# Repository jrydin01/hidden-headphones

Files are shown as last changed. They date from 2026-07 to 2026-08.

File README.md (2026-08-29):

# Hidden Headphones

> **Bone conduction headphones that sit on your collarbone, completely hidden under your shirt.**

Hidden Headphones is an open-source hardware project for a discrete, neckband-style bone conduction audio device. The electronics sit in a small rear enclosure while flexible wiring runs through the neckband to vibration pads positioned on the collarbone. The goal is a hands-free listening device that can be worn beneath a shirt.

This repository contains the design documentation, KiCad source files, firmware, bill of materials, and OpenSCAD enclosure model for the current prototype revision.

---

## Overview & Architecture

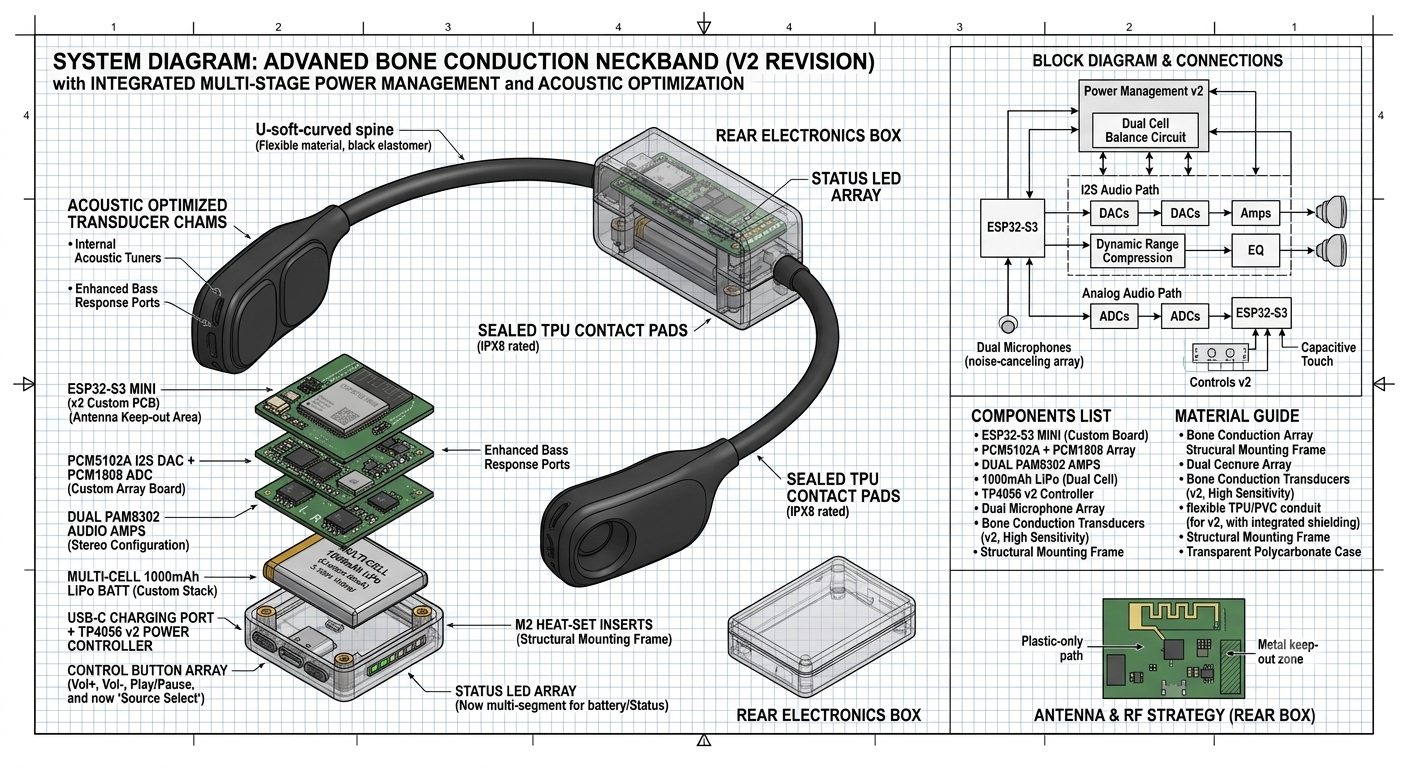
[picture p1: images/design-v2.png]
Design Revision v2


The audio path begins with a phone or computer sending Bluetooth Classic A2DP audio to the original ESP32. The microcontroller outputs stereo PCM audio over I2S to the PCM5102A DAC. Two PAM8302A mono amplifiers drive the left and right bone conduction transducers installed in sealed TPU contact pads.

The project utilizes a custom electronics assembly, dedicated power subsystem, and 3D-printed housing:

* **Core processor:** Original ESP32-WROOM-32 development board with Wi-Fi and Bluetooth Classic
* **Audio input:** Bluetooth A2DP sink running on the ESP32
* **Audio conversion:** PCM5102A stereo I2S DAC
* **Amplification:** Two PAM8302A 2.5 W class-D mono amplifier boards
* **Transducers:** Two 8 ohm, 1 W bone conduction transducers
* **Power:** 3.7 V, 1000 mAh LiPo battery and USB-C TP4056 charging/protection module
* **Controls:** Active-low tactile volume buttons with internal pull-ups
* **Housing:** PETG rear electronics box with flexible TPU neckband sections and sealed contact pads

### Audio and control pins

The current firmware uses the following original ESP32 GPIO assignments:

| Function | GPIO | Notes |
| --- | ---: | --- |
| I2S LRCK / word select | 25 | PCM5102A clock signal |
| I2S BCK / bit clock | 26 | PCM5102A clock signal |
| I2S data out | 22 | PCM5102A serial audio data |
| Volume up | 16 | Active LOW, SW1 |
| Volume down | 17 | Active LOW, SW2 |
| Play/pause | 18 | Active LOW, SW3 |
| Status LED | 19 | LED_STATUS output |

The buttons use a 50 ms software debounce interval. A press changes the Bluetooth sink volume by 10 steps, clamped to the supported range of 0 to 127. The device advertises as **Hidden Headphones**.

## Features

* Hidden collarbone-mounted bone conduction audio
* Wireless Bluetooth A2DP playback
* Stereo output through two independent transducers
* USB-C charging through the TP4056 module
* Dedicated volume up and volume down controls
* Modular rear electronics enclosure
* Flexible cable routing through the neckband
* Open KiCad schematic and PCB source files
* Parametric OpenSCAD enclosure source

## Bill of materials

The complete sourcing list is available in [BOM.csv](BOM.csv). The main assemblies are:

| Category | Part | Quantity |
| --- | --- | ---: |
| Microcontroller | ESP32-WROOM-32 development board | 1 |
| Audio DAC | PCM5102A I2S stereo module | 1 |
| Amplifier | PAM8302A mono amplifier board | 2 |
| Power management | USB-C TP4056 charging and protection module | 1 |
| Battery | 3.7 V 1000 mAh LiPo pack | 1 |
| Audio | Bone conduction transducer, 8 ohm / 1 W | 2 |
| Controls | 6 x 6 x 5 mm tactile push buttons | 3 |
| Hardware | M2 brass heat-set inserts | 4 |
| Wiring | 28 AWG stranded silicone wire | 1 set |
| Printed materials | TPU and PETG filament | 1 spool each |

## Hardware design

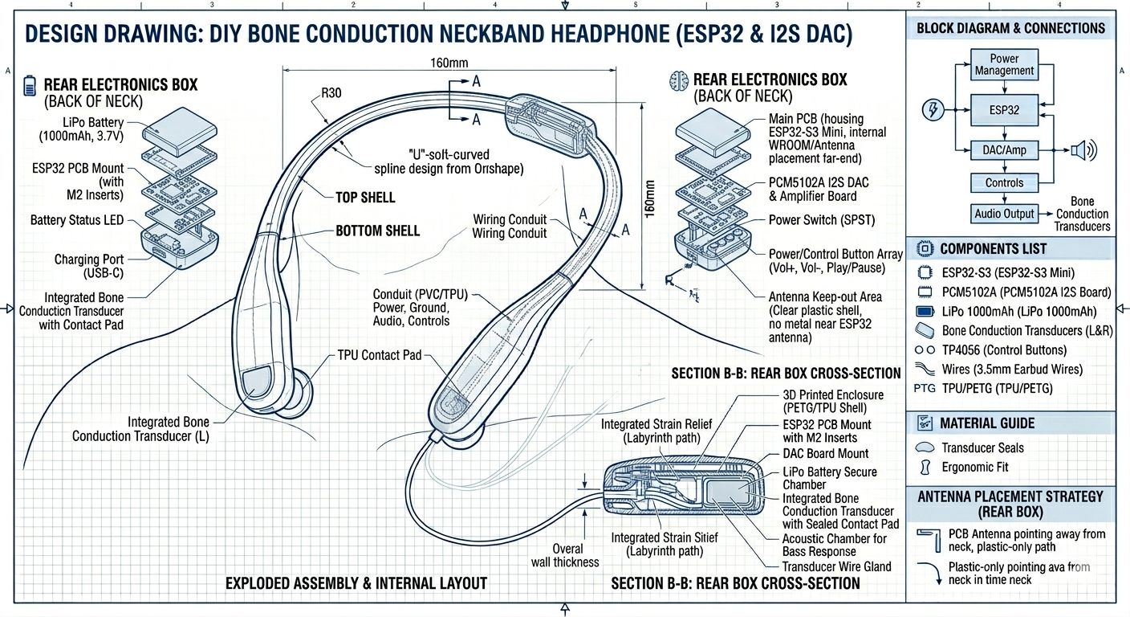
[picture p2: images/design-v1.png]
Design Revision v1


The first design phase established the collarbone contact-pad concept, rear electronics box, battery position, and cable route. The second revision reorganized the electronics around dual amplifier channels and added space for the updated power and audio circuitry.

The rear enclosure is modeled in [rear_box.scad](rear_box.scad). Its current design includes:

* A hollow electronics cavity measuring 55 x 30 x 18 mm internally
* A 2 mm nominal wall thickness
* A USB-C charging-port cutout
* Left and right conduit openings for the neckband wiring
* Four internal PCB mounting posts
* M2 screw and heat-set insert locations
* Separate bottom-case and lid modules for 3D printing

The neckband is intended to use flexible TPU sections for comfort and PETG for the more rigid rear enclosure. The contact pads are designed around sealed TPU housings, with cable strain relief and acoustic tuning features considered in the mechanical revision.

## Firmware

The source firmware is available in [firmware.ino](firmware.ino). It uses the Arduino framework and `ESP32-A2DP` to receive Bluetooth audio and route it over I2S to the PCM5102A and PAM8302A amplifiers. It also handles the three active-low controls and status LED shown in the design diagram.

The firmware currently:

1. Starts a Bluetooth A2DP sink named `Hidden Headphones`.
2. Configures the ESP32 I2S output for the PCM5102A.
3. Enables internal pull-ups for the volume and play/pause buttons.
4. Debounces button input and applies software volume scaling.
5. Controls A2DP playback and the status LED with the play/pause button.
6. Reports startup and control changes over the serial monitor at 115200 baud.

The root-level [firmware.ino](firmware.ino) is also retained as a firmware source snapshot. Keep the two copies synchronized when making firmware changes.

### Flashing and verification

1. Install the ESP32 Arduino board support package and the `ESP32-A2DP` library.
2. Select an original ESP32/WROOM-32 board and its USB serial port.
3. Flash `firmware.ino`.
4. Open a serial monitor at 115200 baud.
6. Confirm the `Bluetooth A2DP sink and PCM5102A I2S output ready` message.
7. Pair a phone or computer with **Hidden Headphones** and verify stereo audio, volume, and play/pause controls.

The pin assignments should be checked against the revised PCB before powering the complete system. The selected GPIOs avoid GPIO0 boot strapping and GPIO1 serial TX conflicts on the ESP32-WROOM-32. The PCB must match this mapping before flashing the firmware.

## Repository structure

```text
.
├── BOM.csv                                      # Component list and sourcing links
├── JOURNAL.md                                   # Project development log and time tracking
├── LICENSE                                      # CC0-1.0 license
├── README.md                                    # Project overview and build guide
├── firmware.ino                                 # Root firmware snapshot
├── firmware.ino                                 # ESP32 Bluetooth A2DP firmware
├── rear_box.scad                                # Parametric rear enclosure model
├── Hidden_Headphones_All_Components_v3.kicad_sch # KiCad schematic
├── Hidden_Headphones_All_Components_v3.kicad_pcb # KiCad PCB layout
├── Hidden_Headphones_All_Components_v3.kicad_pro # KiCad project settings
├── images/                                      # Design, CAD, PCB, and firmware images
└── Untitled/                                    # Additional KiCad working files
```

## Project history

The development log in [JOURNAL.md](JOURNAL.md) records the design process and time spent on each stage:

* **Initial concept:** Established the ESP32 audio architecture, collarbone contact pads, TPU housing, and USB-C rechargeable battery system.
* **CAD and assembly:** Designed the rear electronics box, internal mounting layout, cable conduits, and labyrinth-style strain relief.
* **Component sourcing:** Selected the controller, DAC, amplifiers, charging module, battery, transducers, controls, hardware, wiring, and print materials.
* **Architecture revision:** Added dual PAM8302A amplifiers, revised the power system, and documented the antenna keep-out and sealed contact-pad concepts.
* **Housing model:** Completed the main swept and hollowed enclosure and aligned internal hardware mounting points.
* **PCB design:** Created the KiCad schematic and board layout, resolved schematic and footprint issues, and prepared the design for fabrication.
* **Firmware:** Implemented Bluetooth A2DP playback, I2S routing, volume controls, debouncing, serial output, and the flashing verification procedure.

## Current status

The repository represents a prototype design prepared for hardware fabrication and bring-up. The PCB, firmware, and enclosure should be validated together on assembled hardware, especially the power connections, GPIO assignments, amplifier wiring, battery protection, enclosure clearances, and transducer sealing.

This is an experimental hardware project. Use an appropriate LiPo charging module, inspect batteries and wiring for damage, and do not leave the device charging unattended.

---

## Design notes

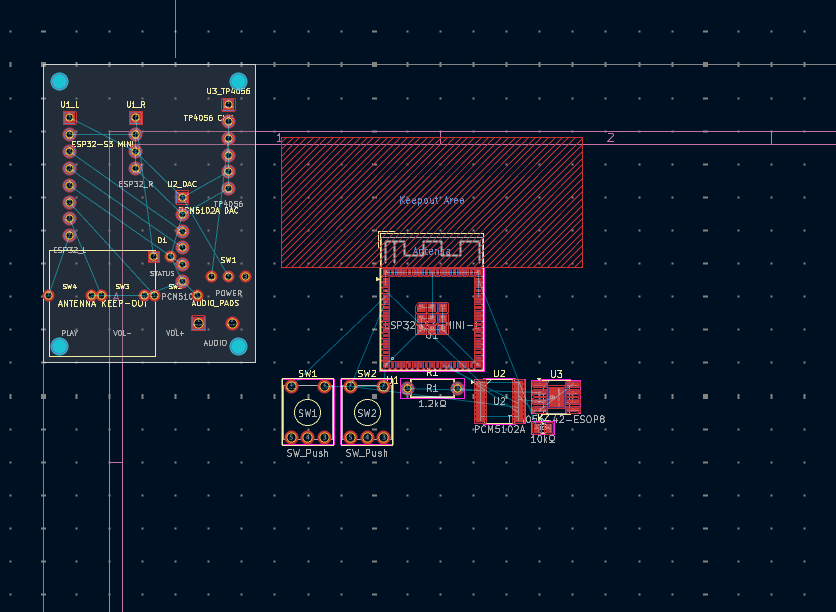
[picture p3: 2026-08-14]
images/pcb_schematic.png

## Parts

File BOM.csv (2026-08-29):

Part Name | Category | Quantity | Description | Link
ESP32-WROOM-32 Board | Microcontroller | 1 | Original ESP32 development board with Wi-Fi and Bluetooth Classic | https://www.aliexpress.com/wholesale?SearchText=ESP32-WROOM-32+development+board
PCM5102A Module | Audio DAC | 1 | I2S Stereo Audio DAC Board | https://www.aliexpress.com/wholesale?SearchText=PCM5102A+I2S+DAC
PAM8302A Board | Amplifier | 2 | 2.5W Class D Mono Audio Amplifier | https://www.aliexpress.com/wholesale?SearchText=PAM8302
TP4056 Module | Power management | 1 | USB-C TP4056 charging and protection module | https://www.aliexpress.com/wholesale?SearchText=TP4056+Type-C
3.7V 1000mAh LiPo Battery | Battery | 1 | 3.7 V 1000 mAh rechargeable LiPo battery pack | https://www.aliexpress.com/wholesale?SearchText=3.7V+1000mAh+LiPo+battery
Bone Conduction Transducers | Audio | 2 | 8 ohm / 1 W bone conduction transducers | https://www.aliexpress.com/wholesale?SearchText=bone+conduction+transducer+speaker
Tactile Push Buttons | Controls | 3 | 6 x 6 x 5 mm tactile push buttons for volume control | https://www.aliexpress.com/wholesale?SearchText=6x6x5mm+tactile+button
M2 Heat-Set Inserts | Hardware | 4 | M2 brass heat-set inserts | https://www.aliexpress.com/wholesale?SearchText=M2+brass+heat+set+inserts
Silicone Wire (28 AWG) | Wiring | 1 set | 28 AWG stranded silicone wire | https://www.aliexpress.com/wholesale?SearchText=28+AWG+silicone+wire
TPU Filament | Printed materials | 1 spool | 1.75 mm black flexible TPU filament | https://www.aliexpress.com/wholesale?SearchText=TPU+filament+black+1.75mm
PETG Filament | Printed materials | 1 spool | 1.75 mm black PETG filament | https://www.aliexpress.com/wholesale?SearchText=PETG+filament+black+1.75mm

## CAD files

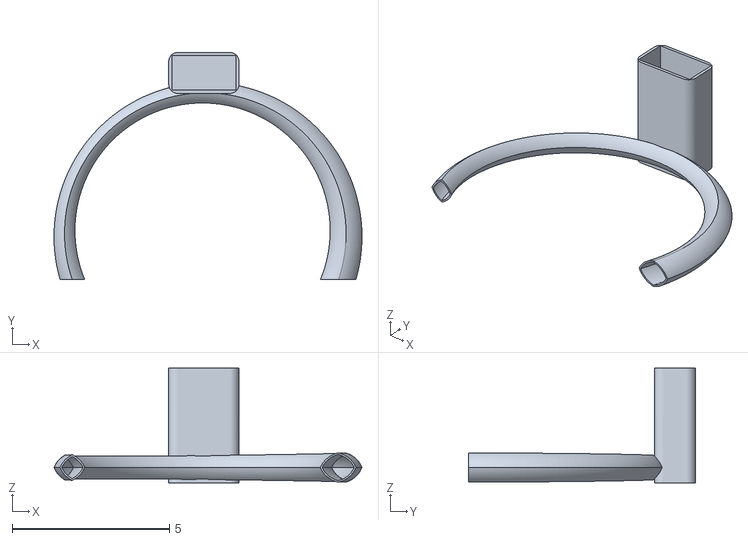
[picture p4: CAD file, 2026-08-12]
neckband - Part 1 2.stl
9.78 x 7.22 x 3.65

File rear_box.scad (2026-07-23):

// ==========================================
// HIDDEN HEADPHONES - REAR ELECTRONICS BOX (V2)
// Designed for 3D Printing (PETG / TPU)
// ==========================================

$fn = 60; // Smooth curves

// --- Dimensions ---
inner_length = 55;
inner_width  = 30;
inner_height = 18;
wall_thick   = 2.0;

box_length = inner_length + (wall_thick * 2);
box_width  = inner_width + (wall_thick * 2);
box_height = inner_height + (wall_thick * 2);
corner_r   = 4.0;

// --- Main Assembly ---
// Uncomment one at a time to export individual STL parts:
main_bottom_case();
// translate([0, 0, 30]) main_top_lid();

// --- Modules ---

module rounded_cube(x, y, z, r) {
    hull() {
        translate([r, r, r]) sphere(r=r);
        translate([x-r, r, r]) sphere(r=r);
        translate([r, y-r, r]) sphere(r=r);
        translate([x-r, y-r, r]) sphere(r=r);
        translate([r, r, z-r]) sphere(r=r);
        translate([x-r, r, z-r]) sphere(r=r);
        translate([r, y-r, z-r]) sphere(r=r);
        translate([x-r, y-r, z-r]) sphere(r=r);
    }
}

module main_bottom_case() {
    difference() {
        // Outer Body
        rounded_cube(box_length, box_width, box_height * 0.7, corner_r);
        
        // Inner Cavity
        translate([wall_thick, wall_thick, wall_thick])
            cube([inner_length, inner_width, inner_height + 5]);
        
        // USB-C Charging Port Cutout (Bottom / Back Edge)
        translate([box_length/2 - 6, -1, wall_thick + 2])
            cube([12, wall_thick + 2, 6]);

        // Conduit Openings (Left and Right for Neckband Wires)
        translate([-1, box_width/2, box_height/2 - 2])
            rotate([0, 90, 0]) cylinder(h=wall_thick + 2, r=3.5);
            
        translate([box_length - wall_thick - 1, box_width/2, box_height/2 - 2])
            rotate([0, 90, 0]) cylinder(h=wall_thick + 2, r=3.5);

        // M2 Screw Heat-Set Insert Holes (Corners)
        screw_holes(h=box_height, r=1.6);
    }
    
    // Internal Mounting Posts for Stacking PCBs
    translate([wall_thick + 4, wall_thick + 4, wall_thick]) cylinder(h=3, r=2.5);
    translate([box_length - wall_thick - 4, wall_thick + 4, wall_thick]) cylinder(h=3, r=2.5);
    translate([wall_thick + 4, box_width - wall_thick - 4, wall_thick]) cylinder(h=3, r=2.5);
    translate([box_length - wall_thick - 4, box_width - wall_thick - 4, wall_thick]) cylinder(h=3, r=2.5);
}

module main_top_lid() {
    difference() {
        // Lid Shell
        rounded_cube(box_length, box_width, box_height * 0.35, corner_r);
        
        // Inner Lip Recess
        translate([wall_thick, wall_thick, -1])
            cube([inner_length, inner_width, box_height * 0.35 - wall_thick + 1]);

        // M2 Screw Countersunk Clearance Holes
        screw_holes(h=box_height, r=1.2);
    }
}

module screw_holes(h, r) {
    translate([wall_thick + 3, wall_thick + 3, -1]) cylinder(h=h, r=r);
    translate([box_length - wall_thick - 3, wall_thick + 3, -1]) cylinder(h=h, r=r);
    translate([wall_thick + 3, box_width - wall_thick - 3, -1]) cylinder(h=h, r=r);
    translate([box_length - wall_thick - 3, box_width - wall_thick - 3, -1]) cylinder(h=h, r=r);
}

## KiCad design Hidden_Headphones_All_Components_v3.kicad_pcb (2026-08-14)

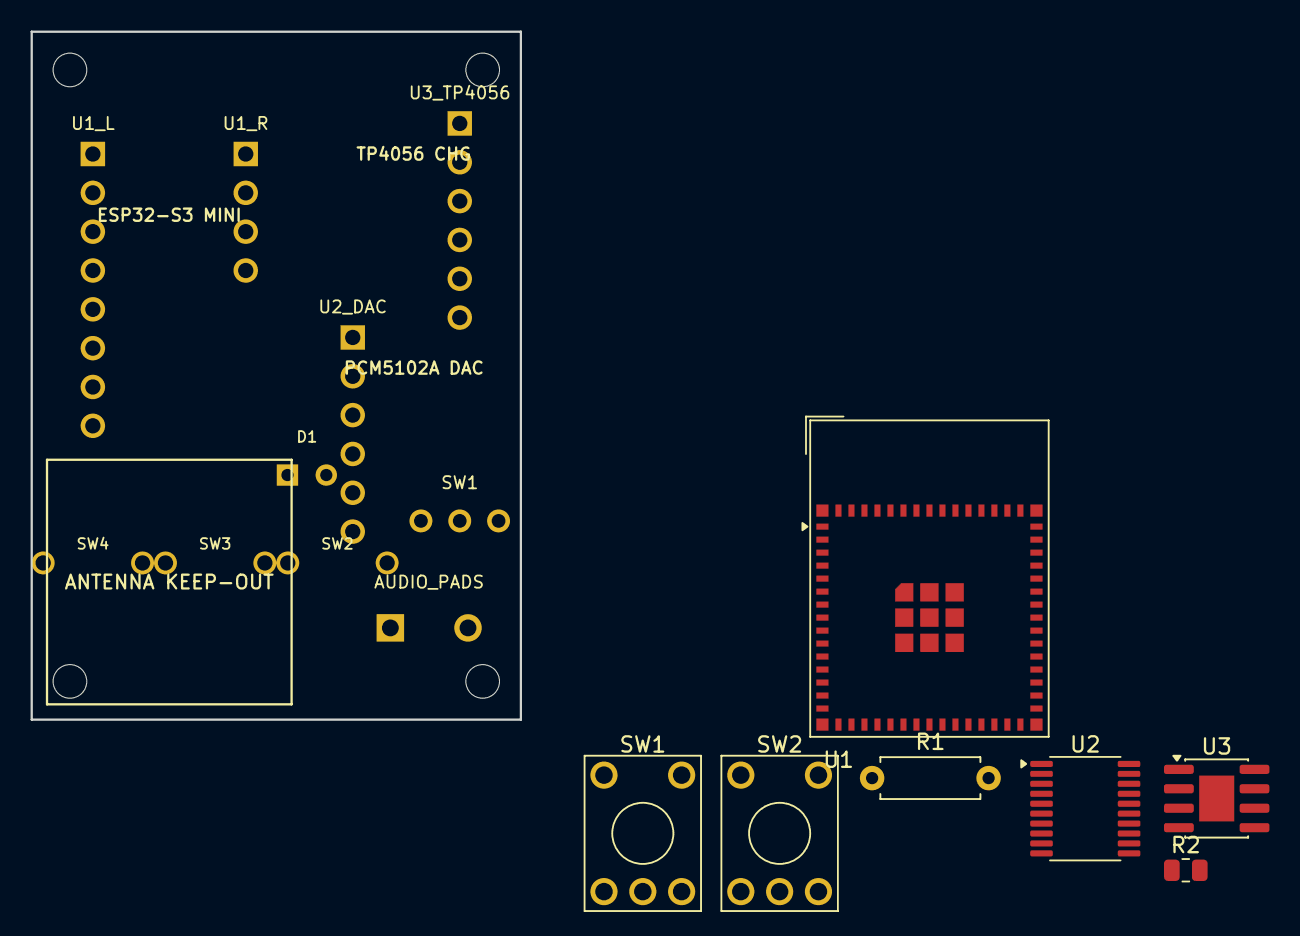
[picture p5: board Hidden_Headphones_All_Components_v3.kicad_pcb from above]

Board: 2 copper layers, 32.0 x 45.0 mm, 17 parts (0 on the bottom side), 20 nets, no tracks yet.

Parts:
AUDIO_PADS: AUDIO; TerminalBlock_bornier-2_P5.08mm
D1: STATUS; LED_D3.0mm
R1: 1.2kΩ; R_Axial_DIN0207_L6.3mm_D2.5mm_P7.62mm_Horizontal
R2: 10kΩ; R_0805_2012Metric
SW1: POWER; SW_Slide_SPDT_EG1218
SW1#2, SW2: SW_Push; KSA_Tactile_SPST
SW2#2: VOL+; SW_PUSH_6mm
SW3: VOL-; SW_PUSH_6mm
SW4: PLAY; SW_PUSH_6mm
U1: ESP32-S3-MINI-1; ESP32-S2-MINI-1
U1_L: ESP32_L; PinHeader_1x08_P2.54mm_Vertical
U1_R: ESP32_R; PinHeader_1x04_P2.54mm_Vertical
U2: PCM5102A; TSSOP-20_4.4x6.5mm_P0.65mm
U2_DAC: PCM5102A; PinHeader_1x06_P2.54mm_Vertical
U3: TP4056-42-ESOP8; SOIC-8-1EP_3.9x4.9mm_P1.27mm_EP2.29x3mm
U3_TP4056: TP4056; PinHeader_1x06_P2.54mm_Vertical

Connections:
+3V3_PWR: SW1.2, U1_L.1, U1_R.3, U2_DAC.1, U3_TP4056.5
BTN_PLAY_PAUSE: SW4.1, U1_L.8
BTN_VOL_DOWN: SW3.1, U1_L.7
BTN_VOL_UP: SW2#2.1, U1_L.6
GND: D1.2, SW2#2.2, SW3.2, SW4.2, U1_L.2, U1_R.2, U1_R.4, U2_DAC.2, U2_DAC.6, U3_TP4056.2, U3_TP4056.4, U3_TP4056.6
I2S_BCK: U1_L.4, U2_DAC.4
I2S_DATA: U1_L.5, U2_DAC.5
I2S_LRCK: U1_L.3, U2_DAC.3
LED_STATUS: D1.1, U1_R.1
unnamed: SW1#2.2, SW2.2, U1.1 (GND), U1.2 (GND), U1.42 (GND), U1.43 (GND), U1.46 (GND), U1.47 (GND), U1.48 (GND), U1.49 (GND), U1.50 (GND), U1.51 (GND), U1.52 (GND), U1.53 (GND), U1.54 (GND), U1.55 (GND), U1.56 (GND), U1.57 (GND), U1.58 (GND), U1.59 (GND), U1.60 (GND), U1.61 (GND), U1.62 (GND), U1.63 (GND), U1.64 (GND), U1.65 (GND)
unnamed: R2.2, U1.3 (3V3), U2.1 (CPVDD), U2.8 (AVDD), U2.17 (XSMT), U2.20 (DVDD)
unnamed: R2.1, U1.45 (EN)
unnamed: SW1#2.1, U1.4 (IO0)
unnamed: SW2.1, U1.5 (IO1), U2.14 (DIN)
unnamed: U1.25 (IO21), U2.15 (LRCK)
unnamed: U1.26 (IO26), U2.13 (BCK)
unnamed: R1.2, U2.3 (CPGND), U2.9 (AGND), U2.10 (DEMP), U2.11 (FLT), U2.12 (SCK), U2.16 (FMT), U2.19 (DGND), U3.3 (GND), U3.9 (EPAD)
unnamed: U3.4 (V_{CC}), U3.8 (CE)
unnamed: R1.1, U3.2 (PROG)
VBAT: SW1.1, U3_TP4056.3

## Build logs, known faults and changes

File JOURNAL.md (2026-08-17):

---
title: "Hidden headphones"
author: "Jaspar Ryding"
description: "bone conduction headphones that sit on your collarbone, hidden under your shirt"
created_at: "23/07/2026"
---

# july 23: started design of headphones
i started designing the prototypes and came up with a design drawing, which entails what the design will look like and how it works. its is based off a esp32 s3 and a small audio amplifier, which connects to the vibration pads, which sit in a tpu housing, making it sweat and dust resistant. it has a small lipo battery which charges using usb-c via a power controller.

design image v1

**total time spent: 40 hours**

---

# july 23: detailed CAD & exploded assembly design
worked on breaking down the full internal layout and exploded assembly for the neckband. finalized the rear electronics box containing the ESP32-S3 Mini, PCM5102A I2S DAC board, and 1000mAh LiPo battery. mapped out the wiring conduits running through the flexible TPU housing down to the contact pads, and designed a labyrinth-style strain relief to keep the wiring durable.

design image v2

**total time spent: 2.5 hours**

---

# july 23: component sourcing & bill of materials
spent time searching for all necessary electronic modules, hardware, and raw materials needed to construct the design. sourced the ESP32-S3 Mini, PCM5102A DAC, TP4056 USB-C charging module, 1000mAh LiPo battery, bone conduction transducers, tactile buttons, M2 heat-set inserts, silicone wiring, and 3D printing filaments from single-supplier options to streamline procurement.

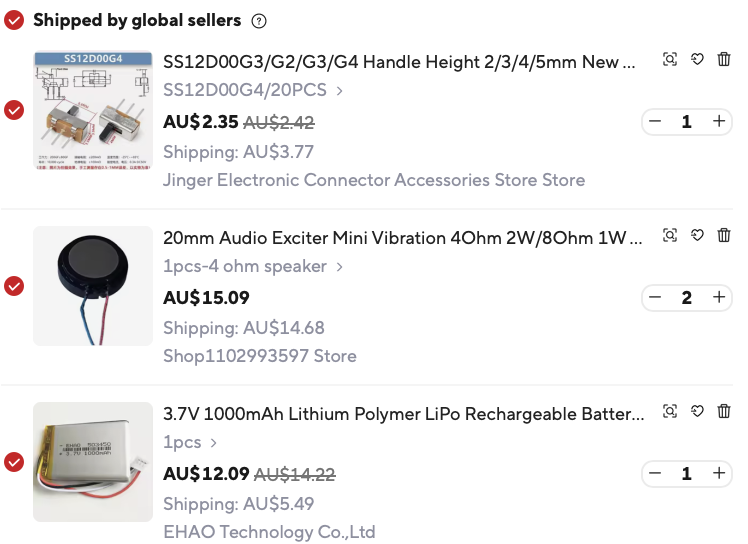
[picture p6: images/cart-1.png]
cart 1


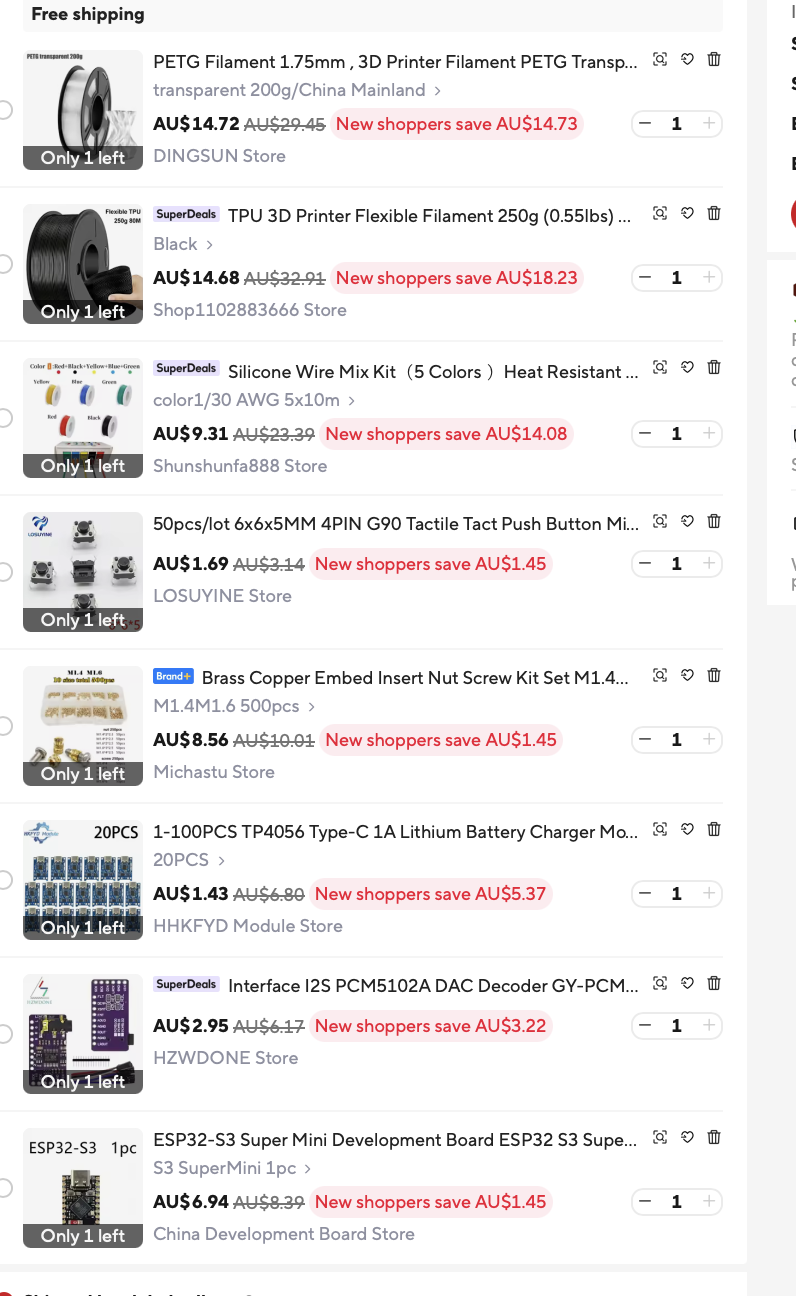
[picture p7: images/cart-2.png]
cart 2


**total time spent: 5 hours**

---

# july 23: v2 design drawing & architecture overhaul
spent significant time re-architecting the system blueprint for the second revision of the headphones. redesigned the rear electronics box to include dual pam8302 amps, pcm1808 adc integration, and an updated multi-cell lipo power management circuit. updated the entire schematic to detail IPX8-rated sealed tpu contact pads, acoustic tuning ports for enhanced bass, and a dedicated antenna keep-out zone for the esp32-s3.

design image v2

**total time spent: 10 hours**

---

# July 31: worked on 3d model of housing
Finally wrapped up this phase of the 3D model for the housing—it took a full 48 hours of back-and-forth iteration, but it’s finally where it needs to be. Designing something that’s supposed to be both functional and comfortable is a real balancing act, and getting the wall thickness right so it’s sturdy without being overly bulky definitely tested my patience.
I managed to get the main enclosure swept and hollowed out properly, along with lining up all the internal mount points for the hardware. After all those hours staring at the screen, it’s really satisfying to see it actually look like a real product instead of just floating sketch lines.
Next step is double-checking all the clearances and tolerances before running a test print or moving on to final assembly tweaks. Glad to have this milestone locked in.
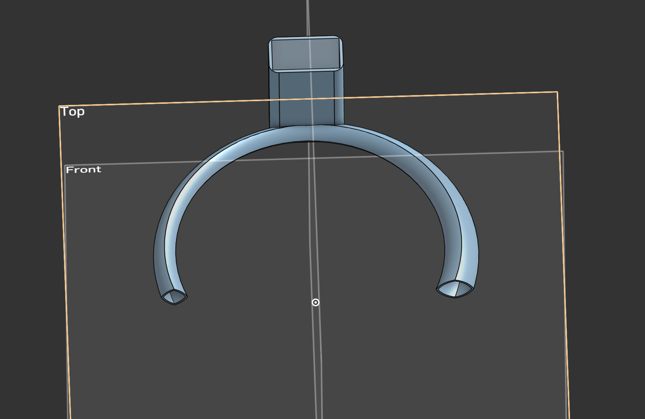
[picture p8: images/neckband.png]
3d model

**total time spent: 48 hours**

---

# August 14: learnt how to make a pcb and did it
After a massive learning curve, I went from having zero idea how custom circuit boards work to completely designing the PCB for the neckband. Learnt the full workflow in KiCad—drawing schematic connections, setting up the power subsystem with the TP4056 charger, and wiring the I2S audio channels between the ESP32-S3 and PCM5102A DAC. Spent hours debugging schematic errors, unmuting the DAC, fixing short circuits, and assigning the right physical footprints to all the push buttons, resistors, and transducers. Once the netlist passed inspection, I pushed everything to the PCB editor, arranged the layout, and prepared the Gerber manufacturing files for fabrication.

pcb schematic

**total time spent: 100 hours**

# August 14: firmware development & flashing guide
With the PCB schematic finalized and ready for fab, I shifted focus to writing the custom firmware for the ESP32-S3 microcontroller. Developed a lightweight C++ application using the PlatformIO environment and the Arduino framework.

Integrated the `ESP32-A2DP` audio sink library to handle Bluetooth A2DP audio streaming directly from a phone or laptop under the device name **"Hidden Headphones"**. The code configures hardware I2S channels (`LRCK` on GPIO21, `BCK` on GPIO26, `DIN` on GPIO1) to route raw PCM audio data straight into the PCM5102A DAC module. Built in software debouncing routines for the active-LOW volume buttons (`SW1` on GPIO0, `SW2` on GPIO1) utilizing internal pull-up resistors to eliminate mechanical switch noise. 

Mapped out a complete flashing procedure, CDC serial output monitoring configuration, and hardware verification strategy for when the physical PCBs arrive from the factory.

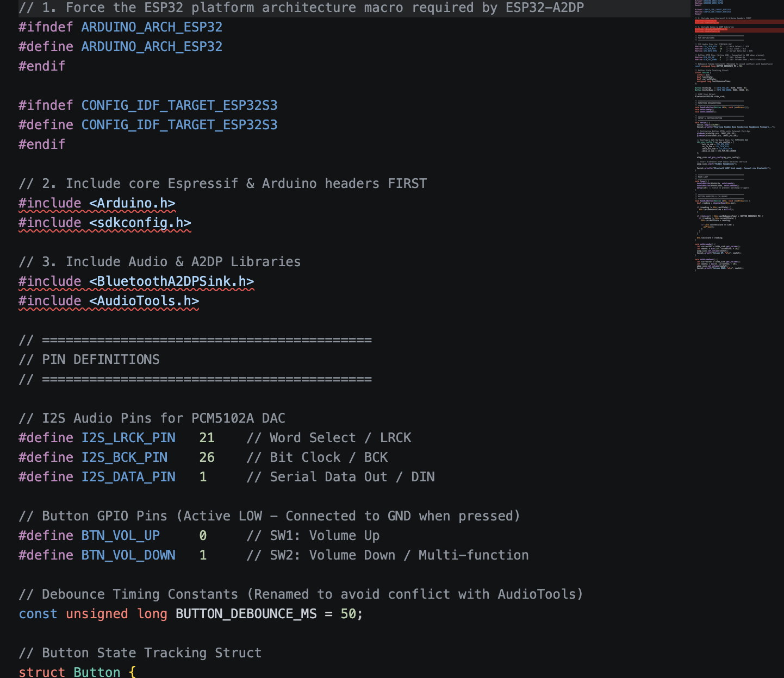
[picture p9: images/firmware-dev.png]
firmware structure


**total time spent: 80 hours**

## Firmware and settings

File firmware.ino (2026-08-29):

/*
 * Hidden Headphones - ESP32 Bluetooth A2DP firmware
 *
 * This sketch targets an original ESP32/WROOM-32 board. Unlike the ESP32-S3,
 * the original ESP32 supports Bluetooth Classic A2DP for phone audio.
 */

#include <Arduino.h>
#include <BluetoothA2DPSink.h>
#include <driver/i2s.h>

// I2S connection to the PCM5102A.
constexpr gpio_num_t I2S_BCK_PIN = GPIO_NUM_26;
constexpr gpio_num_t I2S_LRCK_PIN = GPIO_NUM_25;
constexpr gpio_num_t I2S_DATA_PIN = GPIO_NUM_22;

// Active-low controls from the diagram. Keep these separate from I2S pins.
constexpr gpio_num_t BTN_VOL_UP = GPIO_NUM_16;
constexpr gpio_num_t BTN_VOL_DOWN = GPIO_NUM_17;
constexpr gpio_num_t BTN_PLAY_PAUSE = GPIO_NUM_18;
constexpr gpio_num_t LED_STATUS = GPIO_NUM_19;

constexpr uint32_t BUTTON_DEBOUNCE_MS = 50;
constexpr int16_t VOLUME_STEP = 10;
constexpr int16_t MAX_VOLUME = 127;

BluetoothA2DPSink a2dpSink;

struct Button {
  gpio_num_t pin;
  bool lastReading;
  bool stableState;
  uint32_t lastChangeMs;
  void (*onPress)();
};

int16_t volume = 64;
bool playing = true;

void onVolumeUp();
void onVolumeDown();
void onPlayPause();

Button buttons[] = {
    {BTN_VOL_UP, HIGH, HIGH, 0, onVolumeUp},
    {BTN_VOL_DOWN, HIGH, HIGH, 0, onVolumeDown},
    {BTN_PLAY_PAUSE, HIGH, HIGH, 0, onPlayPause},
};

void configureI2S() {
  i2s_pin_config_t pins = {};
  pins.bck_io_num = I2S_BCK_PIN;
  pins.ws_io_num = I2S_LRCK_PIN;
  pins.data_out_num = I2S_DATA_PIN;
  pins.data_in_num = I2S_PIN_NO_CHANGE;
  a2dpSink.set_pin_config(pins);
}

void handleButton(Button &button) {
  const bool reading = digitalRead(button.pin);
  const uint32_t now = millis();

  if (reading != button.lastReading) {
    button.lastChangeMs = now;
    button.lastReading = reading;
  }

  if (now - button.lastChangeMs >= BUTTON_DEBOUNCE_MS && reading != button.stableState) {
    button.stableState = reading;
    if (button.stableState == LOW) {
      button.onPress();
    }
  }
}

void onVolumeUp() {
  volume = min<int16_t>(MAX_VOLUME, a2dpSink.get_volume() + VOLUME_STEP);
  a2dpSink.set_volume(volume);
  Serial.printf("Volume UP: %d/127\n", volume);
}

void onVolumeDown() {
  volume = max<int16_t>(0, a2dpSink.get_volume() - VOLUME_STEP);
  a2dpSink.set_volume(volume);
  Serial.printf("Volume DOWN: %d/127\n", volume);
}

void onPlayPause() {
  playing = !playing;
  if (playing) {
    a2dpSink.play();
  } else {
    a2dpSink.pause();
  }
  digitalWrite(LED_STATUS, playing ? HIGH : LOW);
  Serial.printf("Playback %s\n", playing ? "started" : "paused");
}

void setup() {
  Serial.begin(115200);
  delay(200);
  Serial.println("Starting Hidden Headphones ESP32 Bluetooth A2DP firmware");

  pinMode(LED_STATUS, OUTPUT);
  digitalWrite(LED_STATUS, HIGH);
  for (Button &button : buttons) {
    pinMode(button.pin, INPUT_PULLUP);
  }

  configureI2S();
  a2dpSink.start("Hidden Headphones");
  a2dpSink.set_volume(volume);
  Serial.println("Bluetooth A2DP sink and PCM5102A I2S output ready");
}

void loop() {
  for (Button &button : buttons) {
    handleButton(button);
  }
}

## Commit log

2026-07-23 cad files
    [rear_box.scad]
2026-08-14 worked on pcb
    [Hidden_Headphones_All_Components_v3.kicad_pcb, Hidden_Headphones_All_Components_v3.kicad_sch]
2026-08-17 rough firmware creation and editing pcb
    [Hidden_Headphones_All_Components_v3.kicad_sch]
2026-08-28 edited bom
    [BOM.csv]
2026-08-29 started pcb redesign, redid firmware for it
    [BOM.csv, Hidden_Headphones_All_Components_v3.kicad_sch]
